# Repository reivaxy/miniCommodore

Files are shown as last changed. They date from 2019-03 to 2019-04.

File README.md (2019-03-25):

This is a miniature Commodore PET model equipped with an esp8266 board and a 64x128 oled display

It can open a wifi access point and connect to a wifi network and display stuff.
What it does depends on what you flash in it.

Prototype features a temperature/pressure/humidity sensor.

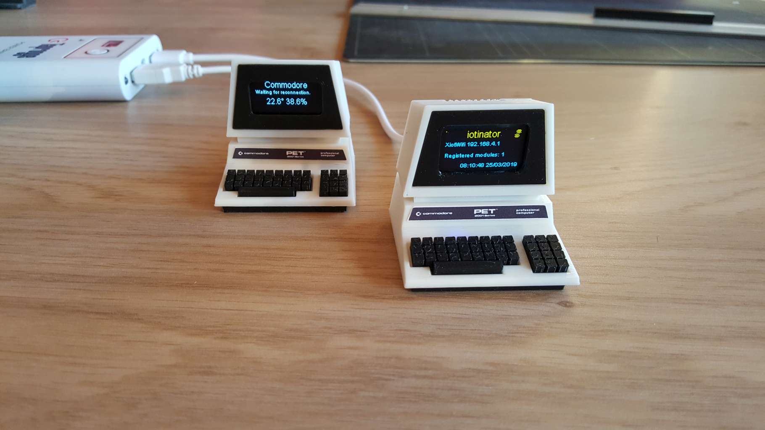
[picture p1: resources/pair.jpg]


Roadmap:

Make more room in the base and body, try to power it using a small lipo battery (and power switch), set microswitches under the keyboards bound to ESP inputs to control program features...

And make a few games available.

Its first use is to host the iotinator master module (https://github.com/reivaxy/iotinator)

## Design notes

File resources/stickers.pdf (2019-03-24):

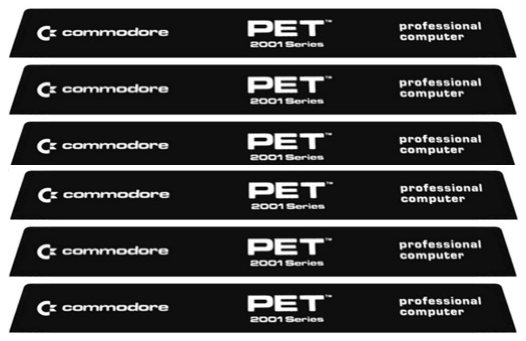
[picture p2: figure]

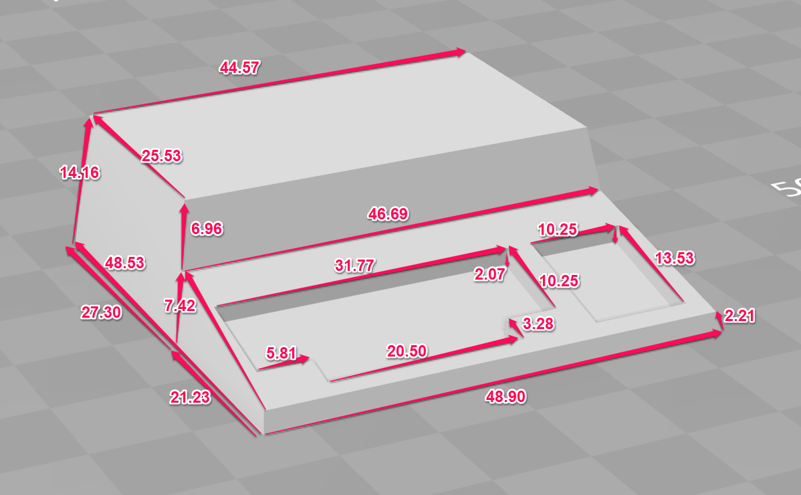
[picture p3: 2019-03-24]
resources/bodyDimensions.png

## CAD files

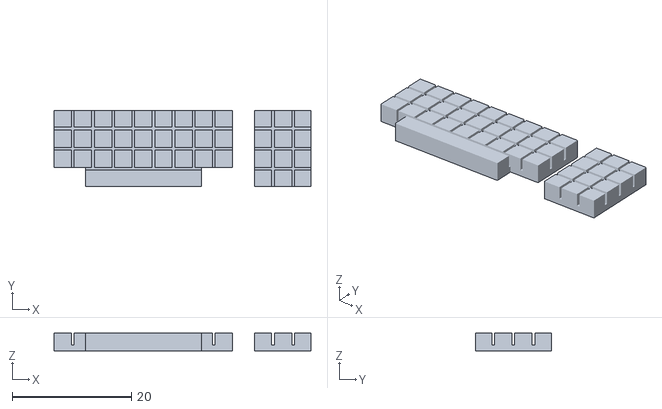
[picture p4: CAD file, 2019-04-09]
keys.stl
43.2 x 12.8 x 3.00

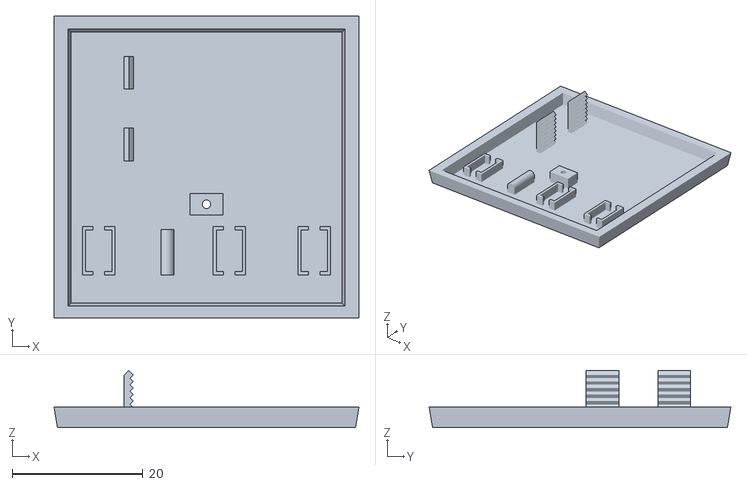
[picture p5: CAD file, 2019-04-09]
base.stl
46.7 x 46.2 x 8.78

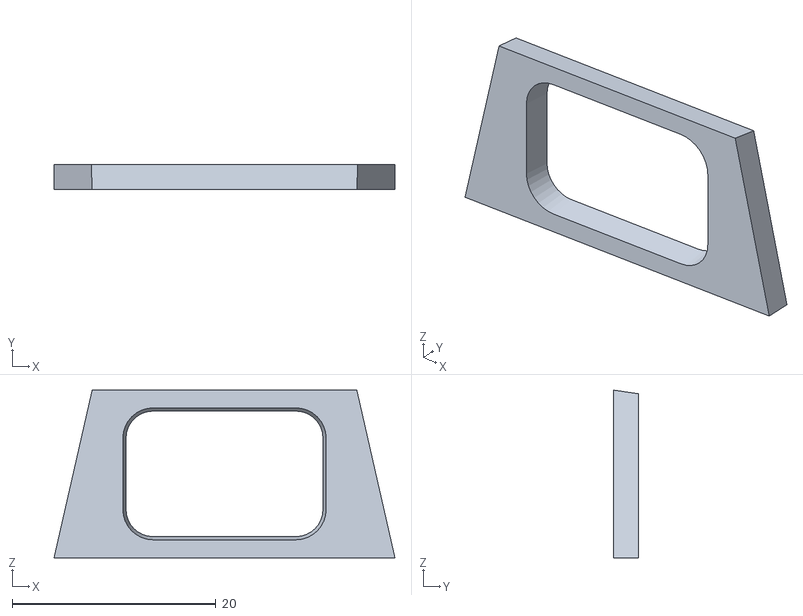
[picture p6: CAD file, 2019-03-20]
sources/monitor_frame.stl
33.4 x 2.50 x 16.5

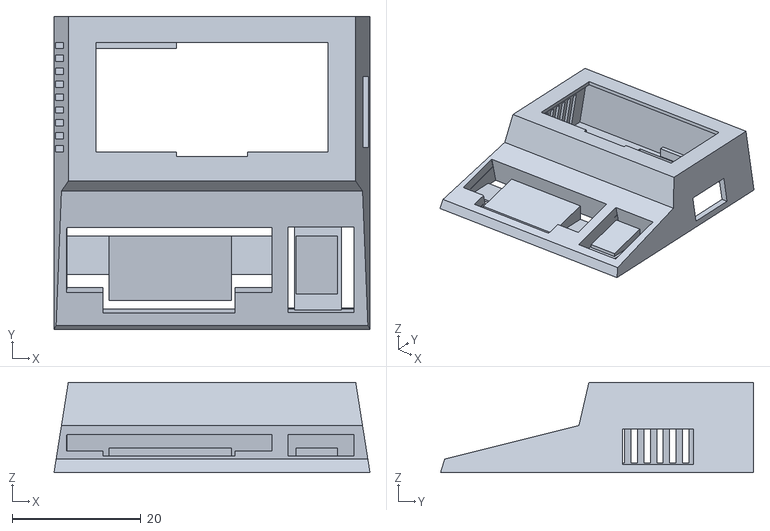
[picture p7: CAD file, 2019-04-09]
body.stl
49.0 x 48.5 x 14.0

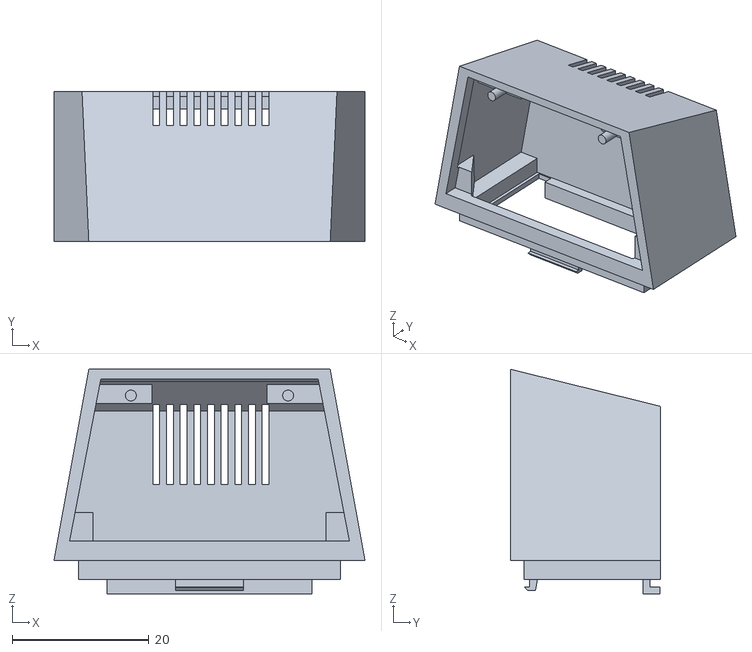
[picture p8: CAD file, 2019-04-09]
monitor.stl
45.5 x 22.0 x 32.8

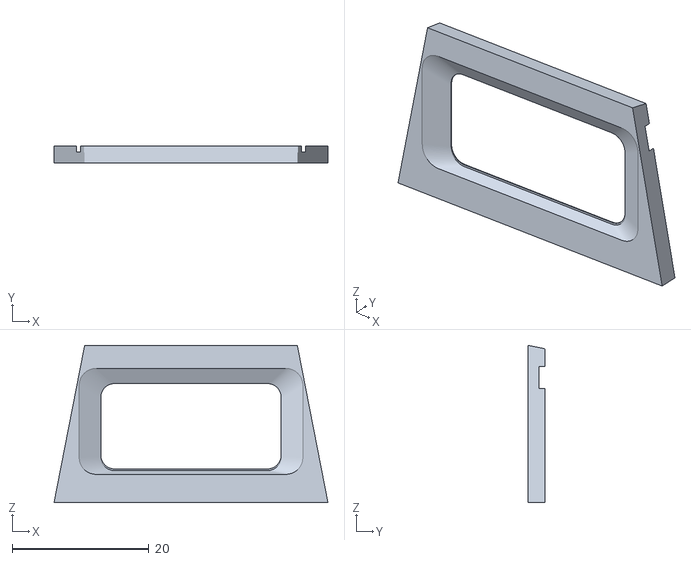
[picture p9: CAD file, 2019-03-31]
monitorFrameChamfered.stl
40.1 x 2.50 x 23.0

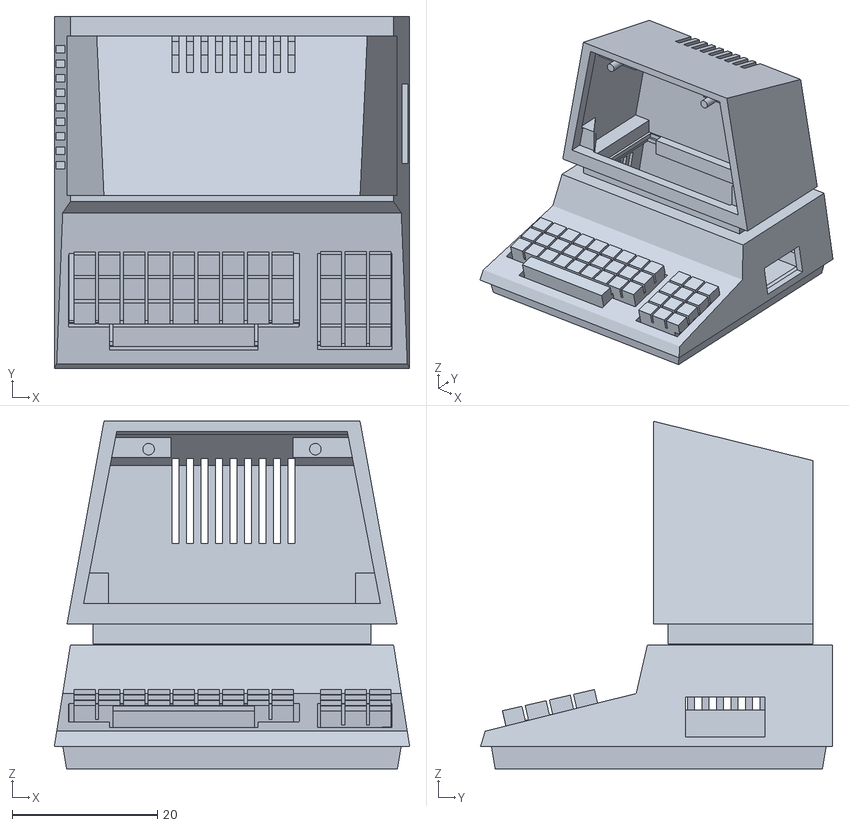
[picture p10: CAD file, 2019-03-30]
commodore.stl
49.0 x 48.5 x 47.9

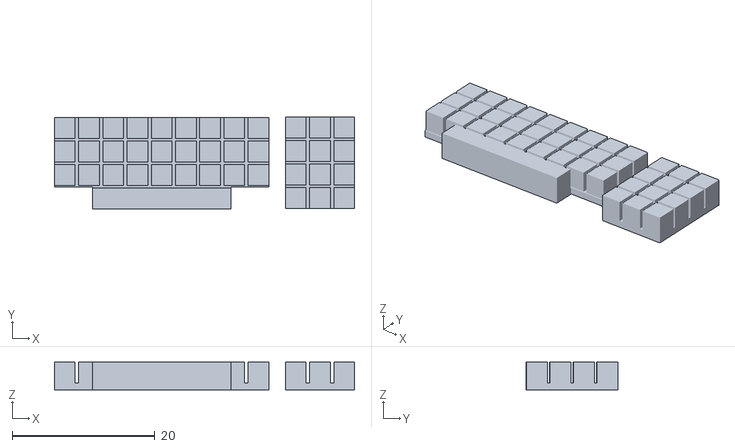
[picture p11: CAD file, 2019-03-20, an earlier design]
sources/keys.stl
42.1 x 12.9 x 3.88

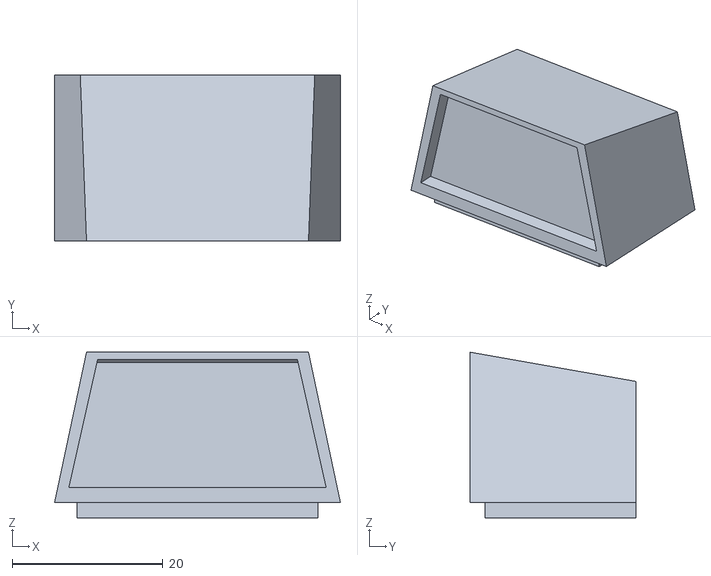
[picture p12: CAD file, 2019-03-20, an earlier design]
sources/monitor.stl
37.9 x 22.0 x 22.0

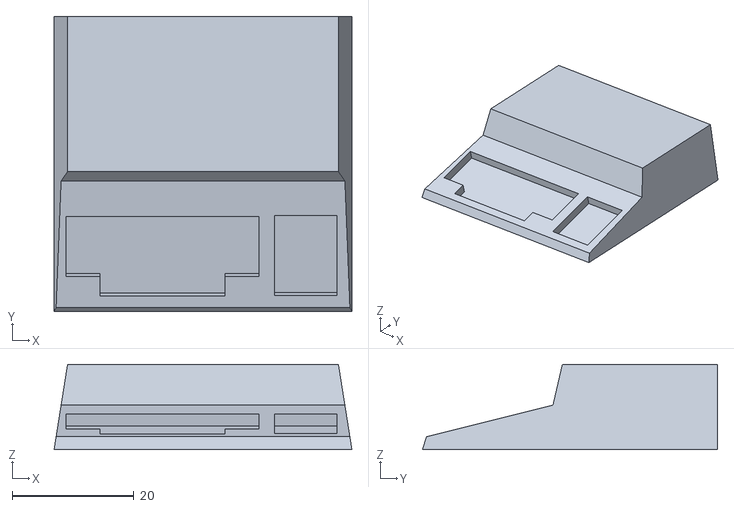
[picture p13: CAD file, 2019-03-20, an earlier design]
sources/body.stl
49.0 x 48.5 x 14.0

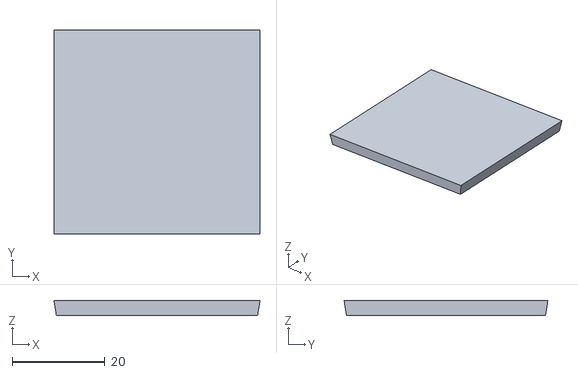
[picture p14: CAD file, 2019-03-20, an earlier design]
sources/base.stl
44.5 x 44.0 x 3.15

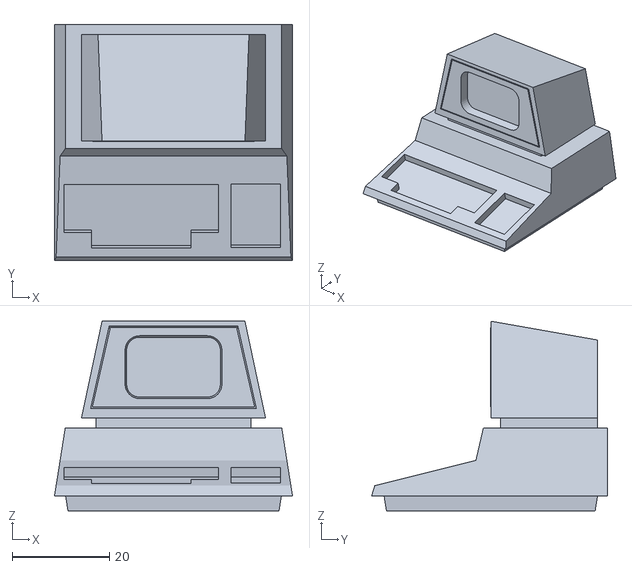
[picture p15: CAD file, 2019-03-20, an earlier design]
sources/commodore.stl
49.0 x 48.5 x 39.0

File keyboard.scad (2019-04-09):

include <globals.scad>;
                                      

rowCount = 3;
colCount = 9;
keyInterval = 0.45;
keySide = (keyboardX - (colCount - 1)*keyInterval) / colCount;

module keyboard(switch, print) {
  if(switch == 0) {
    paramKeyboard(4);
  } else {
    paramKeyboard(3);
  } 
}

module paramKeyboard(z) {
  *import(file="sources/keys.stl");
  
  translate([-21.8, -17.3, 0]) {
    difference() {
      pads(z);
      // draw rows
      translate([0, -keyInterval, 0])
      for (row = [0 : rowCount]) {
        translate([-keyInterval, row*(keySide + keyInterval), z-2]) {
          cube([keyboardX + 50, keyInterval, 5]);
        }
      }
  
      // draw columns
      translate([-keyInterval, 0, 0])
      for (col = [1 : colCount + 5]) {
        if(col > colCount) {
          translate([1.7+keySide/2 + col*(keySide + keyInterval), -keySide-1, z-2]) {
            cube([keyInterval, keyboardY + 20, 5]);
          }
        } else {
          translate([col*(keySide + keyInterval), 0, z-2]) {
            cube([keyInterval, keyboardY + 20, 5]);
          }
        }
      }
  
    }
  }
}

module pads(z) {
  union() {
    cube([keyboardX, keyboardY, z]);
    // Space bar
    translate([(keyboardX - spaceBarX)/2, - spaceBarY - keyInterval, 0]) {
      cube([spaceBarX, spaceBarY + keyInterval, z]);
    }
    // Numeric keypad
    translate([keyboardX + 3.7, -keySide - keyInterval + 0.2, 0]) {
      cube([keyPadX, keyPadY, z]);
    }
  }
}

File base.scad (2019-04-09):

include <globals.scad>;
                   

module base(switch) {
  scale([1.05, 1.05, 1]) {
    difference() {
      import(file="sources/base.stl");
      scale([0.91, 0.92, 0.89]) {
        import(file="sources/base.stl");
      }
      translate([0, -4.45, -5.6]) {
        screw(1);
      }
    }
  }
  if(switch == 1) {
    kbSupport();
  }
  
  // Center screw pillar
  translate([0-2.5, -6.3, -5.5]) {
    difference() {
      cube([screwPillarX, screwPillarY, 3]);
      translate([screwPillarX/2, screwPillarY/2, 0]) {
        screw(1);
      }
    }    
  }
  
  // esp bottom blocking pillar
  translate([-12.6, 2, -5.5]) {
    espBlocker();
  }
  translate([-12.6, 13, -5.5]) {
    espBlocker();
  }
    
}

module espBlocker() {
  cube([0.7, 5, 8]);
  for (slot = [1 : 8]) {
    translate([0, 0, slot]) {
      rotate([0, 45, 0])
        cube([1, 5, 1]);
    }
  }
}
module kbSupport() {
  translate([3, -15.5, -7])  {
    
    translate([-2.0, 0, 0]) {
      switchSupport(switchDownZ, switchFootZ, 0);
    }
    translate([-22.0, 0, 0])  {
      switchSupport(switchDownZ, switchFootZ, 0);
    }
    
    // under keypad
    translate([11, 0, 0])  {
      switchSupport(switchDownZ, switchFootZ, 0);
    }
    // middle pivot
    translate([-10, 0, 2])  {
      cube([2, 7, 1.5]);
      translate([1, 0, 1.5]) {         
        rotate([-90, 0, 0]) {
          cylinder(d=2, h=7, $fn=90);
        }
      }
    }    
  }
  
}
switchDownZ = 2.1;
switchFootZ = 4;
pinX = 1.8;
railSide = 2;

module switchSupport(depth, height, angle) {
  difference() {
    rotate([angle, 0, 0]) {
      straightSupport(depth, height);
    }
    // cut bottom
    translate([-10, -10, 0])
      cube([20, 20, 2]);
  }
}

module straightSupport(depth, height) {
  difference() {
    cube([switchFootX, switchFootY, height]);
    // hole for switch
    translate([(switchFootX - switchX) / 2, (switchFootY - switchY) / 2, height - depth]) {
      cube([switchX, switchY, depth + 1]);
    }
    // slots for switch pins
    translate([(switchFootX - pinX) / 2, -0.5, height - depth]){
      cube([pinX, switchFootY + 1, depth + 1]);
    }
  }
}

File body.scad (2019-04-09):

include <globals.scad>;

module body(switches) {
  difference() {
    import(file="sources/body.stl");
    // Hollow out
    translate([0, 0.9, 0.35]) {
      scale([hollowRatio, 0.93, 0.90]) {
        difference() {
          import(file="sources/body.stl");
          // Remove keyboard from hollowing reduced body to avoid too thin shells
          translate([-25, -29, -4]) {
            cube([50, 22, 8]);
          }
        }
      }

    }
    // body top opening
    translate([-bodyTopOpeningX/2, 4, 10]) {
      cube([bodyTopOpeningX, bodyTopOpeningY, 3]);
    }

    // bottom opening
    translate([-bodyBotOpeningX/2, -bodyBotOpeningY/2 + 15, -5]) {
      cube([bodyBotOpeningX, bodyBotOpeningY - 15, 4]);
    }

    // Under keyboard: if no keyboard switches
    if(switches < 1) {
      translate([-bodyBotOpeningX/2, -bodyBotOpeningY/2 + 1, -7.4]) {
        rotate(13, [1, 0, 0]) {
          cube([bodyBotOpeningX, 15, 5]);
        }
      }
    } else {
      // Remove key pad 
      translate([11.8, -18.9, -8]) {
        rotate(13, [1, 0, 0]) {
          cube([keyPadHoleX, keyPadHoleY, 10]);
        }
      }

    // Remove main keyboard
      translate([-22.5, -15.75, -8]) {
        rotate(13, [1, 0, 0]) {
          cube([keyboardHoleX, keyboardHoleY, 10]);
          // spacebar
          translate([5.6, -3.28, 0]) {
            cube([spaceBarHoleX, spaceBarHoleY, 10]);
          }
        }
      }    
    }
    
    // back left usb
    *translate([-11.5, 3, -1])
      cube([10, 22.5, 5.5]);
    
    // back right usb
    *translate([3, 3, -1])
      cube([10, 22.5, 5.5]);
    
    // right side usb
    translate([20, 4.7, -1.2])
      cube([5, 11, 5.5]);

    // bottom cut along the esp board to free the connectors on the back side
    // back right usb
    translate([-5.5, 18, -3])
      cube([25, 5, 3]);
    
    // right cut along the esp board to allow mounting
    translate([17.5, -1, -3])
      cube([5, 24, 3]);
    
    
    // right side slots
    *for (slot = [0 : 8]) {
      translate([21.5, 4 + slot*2, -1]) {
        cube([3, 1, 8]);
      }
    }
    
    // left side slots
    for (slot = [0 : 8]) {
      translate([-24.5, 4 + slot*2, -1]) {
        cube([3, 1, 8]);
      }
    }
    
    // Space for screen bottom lug
    translate([-5.5, 3.3, 10]) {
      cube([11, 0.9, 3]);
    }
  }


  // right keyboard spring blade 
  translate([2.6, -15, -2.5]) {
    cube([7 , 6, 0.45]);
  } 
  // left keyboard spring blade 
  translate([-23, -15, -2.5]) {
    cube([7, 6, 0.45]);
  }
  // Keyboard support
  difference() {
    translate([-16, -19, -2.5]) {
      cube([keyboardX - 11, 10, 8]);
    }  
   translate([-16.5, -19, -1]) {
      rotate([13, 0, 0])
      cube([20, 15, 8]);
    }    
  }
  
  // keypad spring blade 
  translate([12.8, -20.9, -2.5]) {
    cube([keyPadHoleX - 3 , keyPadHoleY, 1]);
  }  
  // Keypad support
  difference() {
    translate([13, -18, -2.5]) {
      cube([keyPadX - 3, 9, 8]);
    }  
    translate([12, -19, -1]) {
      rotate([13, 0, 0])
      cube([20, 15, 8]);
    }    
  }
  
  // Under top keyboard needs some reinforcement
  translate([-bodyBotOpeningX/2 - 3, -bodyBotOpeningY/2 + 13, 2.75]) {
    rotate(14, [1, 0, 0]) {
      cube([bodyBotOpeningX + 6, 6.2, 0.5]);
    }
  }
  
  // Center screw pillar
  translate([-2.5, -6.3, -2.5]) {
    difference() {
      cube([screwPillarX, screwPillarY, 6.2]);
      translate([screwPillarX/2, screwPillarY/2, 0]) {
        screw(0);
      }
    }
  }
  
  translate([0, 23.2, -2])
    cube([10, 1, 2]);
}
    

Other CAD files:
monitorFrame.stl
commodore.scad
globals.scad
monitor.scad
oledPanel.scad

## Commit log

2019-03-20 Screen openings, sensor supports and slits
    [commodore.scad]
2019-03-22 Version used for first functionnal prototype. Need to improve internal layout (heat...), maonitor frame dimension, hole for screw, ...
    [base.stl, body.stl, commodore.scad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]
2019-03-23 Few adjustments for version 1.0
    [body.stl, commodore.scad, monitor.stl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]
2019-03-23 Begining of v2: Refactoring to split into different files Maximized inner space to house more electronics!
    [base.scad, body.scad, commodore.scad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]
2019-03-24 Before keyboard modifications
    [base.stl, body.scad, body.stl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]
2019-03-24 Added param to display frame or not, or only
    [commodore.scad, monitor.scad]
2019-03-24 Usb opening and various adjustments
    [body.scad, body.stl, commodore.scad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]
2019-03-24 "isolated" compartment for temperature sensor
    [base.scad, base.stl, body.scad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]
2019-03-25 Adjusted adjustments
    [commodore.scad, monitor.scad]
2019-03-25 Removed "Weather" customization after merge from "weather" branch. New picture for Readme
    [body.scad, commodore.scad, monitor.scad]
2019-03-25 Removed 'weather' separation element in base Added complete stl model
    [base.scad, base.stl, commodore.scad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]
2019-03-25 regenerated body stl without 'weather' compartment
    [body.stl]
2019-03-25 Slots on both sides Reinforcement of surface above keyboard
    [body.scad]
2019-03-25 Begining of main keyboard axle support
    [base.scad, body.scad, body.stl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]
2019-03-26 Adding pivot for main keyboard, and switch supports underneath it
    [base.scad, commodore.scad, xbase.stl]
2019-03-29 Still adjusting switch positioning. Failed numeric keypad switch cap, need to find another solution
    [base.scad, commodore.scad, globals.scad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]
2019-03-29 Another failed attempt. Doesn't print well enough
    [base.scad, keyboard.scad]
2019-03-29 Keypad foot slides inside switch compartment. Keypad can fall, not great. But working
    [base.scad, keyboard.scad]
2019-03-29 USB moved to the right Monitor frame chamfered for better view from above
    [body.scad, monitor.scad]
2019-03-29 Updated STL
    [base.stl, body.stl, commodore.scad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]
2019-03-29 a keyboard needs keys !
    [keyboard.scad, keys.stl]
2019-03-30 Keypad switch printed-tested solution, but requires some post processing to cut some plastic.
    [base.scad, body.scad]
2019-03-30 added fixing lugs between body and monitor screw to hold base to body, usb on right side
    [base.scad, base.stl, body.scad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]
2019-03-31 Improved esp blocker in base Moved front lug from body (silly me) to monitor. Doesn't print too well, but it holds the monitor, kind of.
    [base.scad, base.stl, body.scad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]
2019-04-08 First test with spring blades for main keyboard. Not good.
    [base.scad, body.scad, commodore.scad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]
2019-04-09 finalized spring blades mounted keyboard
    [base.scad, base.stl, body.scad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]
